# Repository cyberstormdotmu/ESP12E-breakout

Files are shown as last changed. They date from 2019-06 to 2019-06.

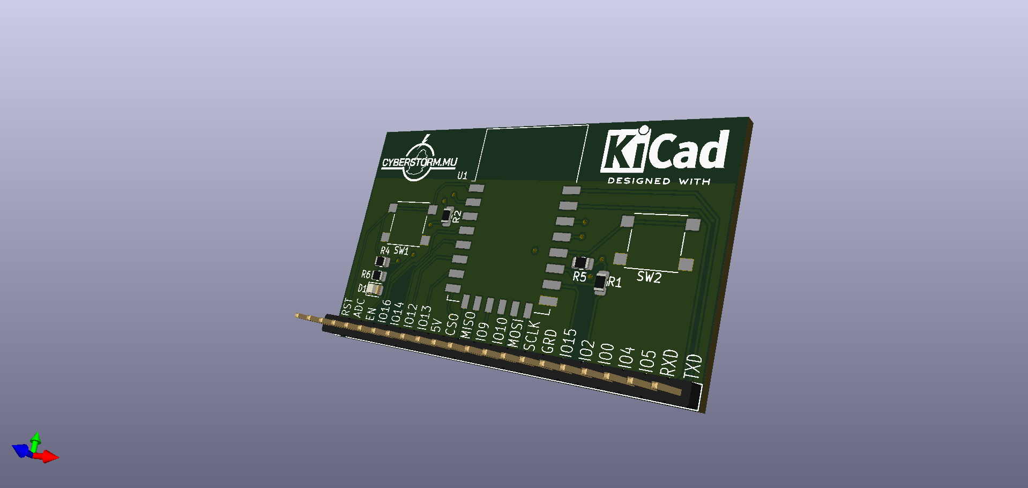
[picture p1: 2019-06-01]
ESP12-E breakout board.png

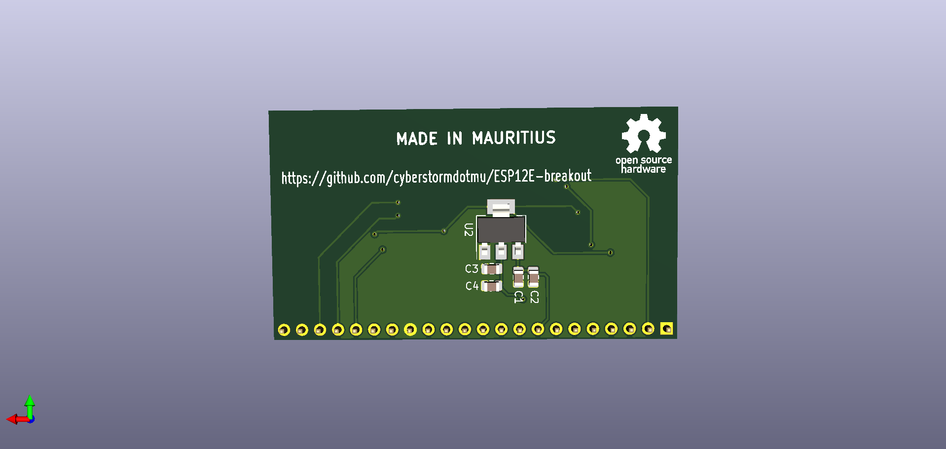
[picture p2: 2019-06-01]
ESP12-E breakout board(back).png

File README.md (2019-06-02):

# ESP12E-breakout
A simple and open source ESP12E/ ESP8266 breakout board. You will need an external programmer to program the module but most of the components required to run the module are present. Made with KiCad.

To open the schematic and pcb file you will need KiCad.

Schematic pdf and PCB photos are provided.

breakoutesp12e.zip is a gerber file.

If you have any questions regarding the design or find any issues then just email me at nathan@cyberstorm.mu

Happy Hacking :)

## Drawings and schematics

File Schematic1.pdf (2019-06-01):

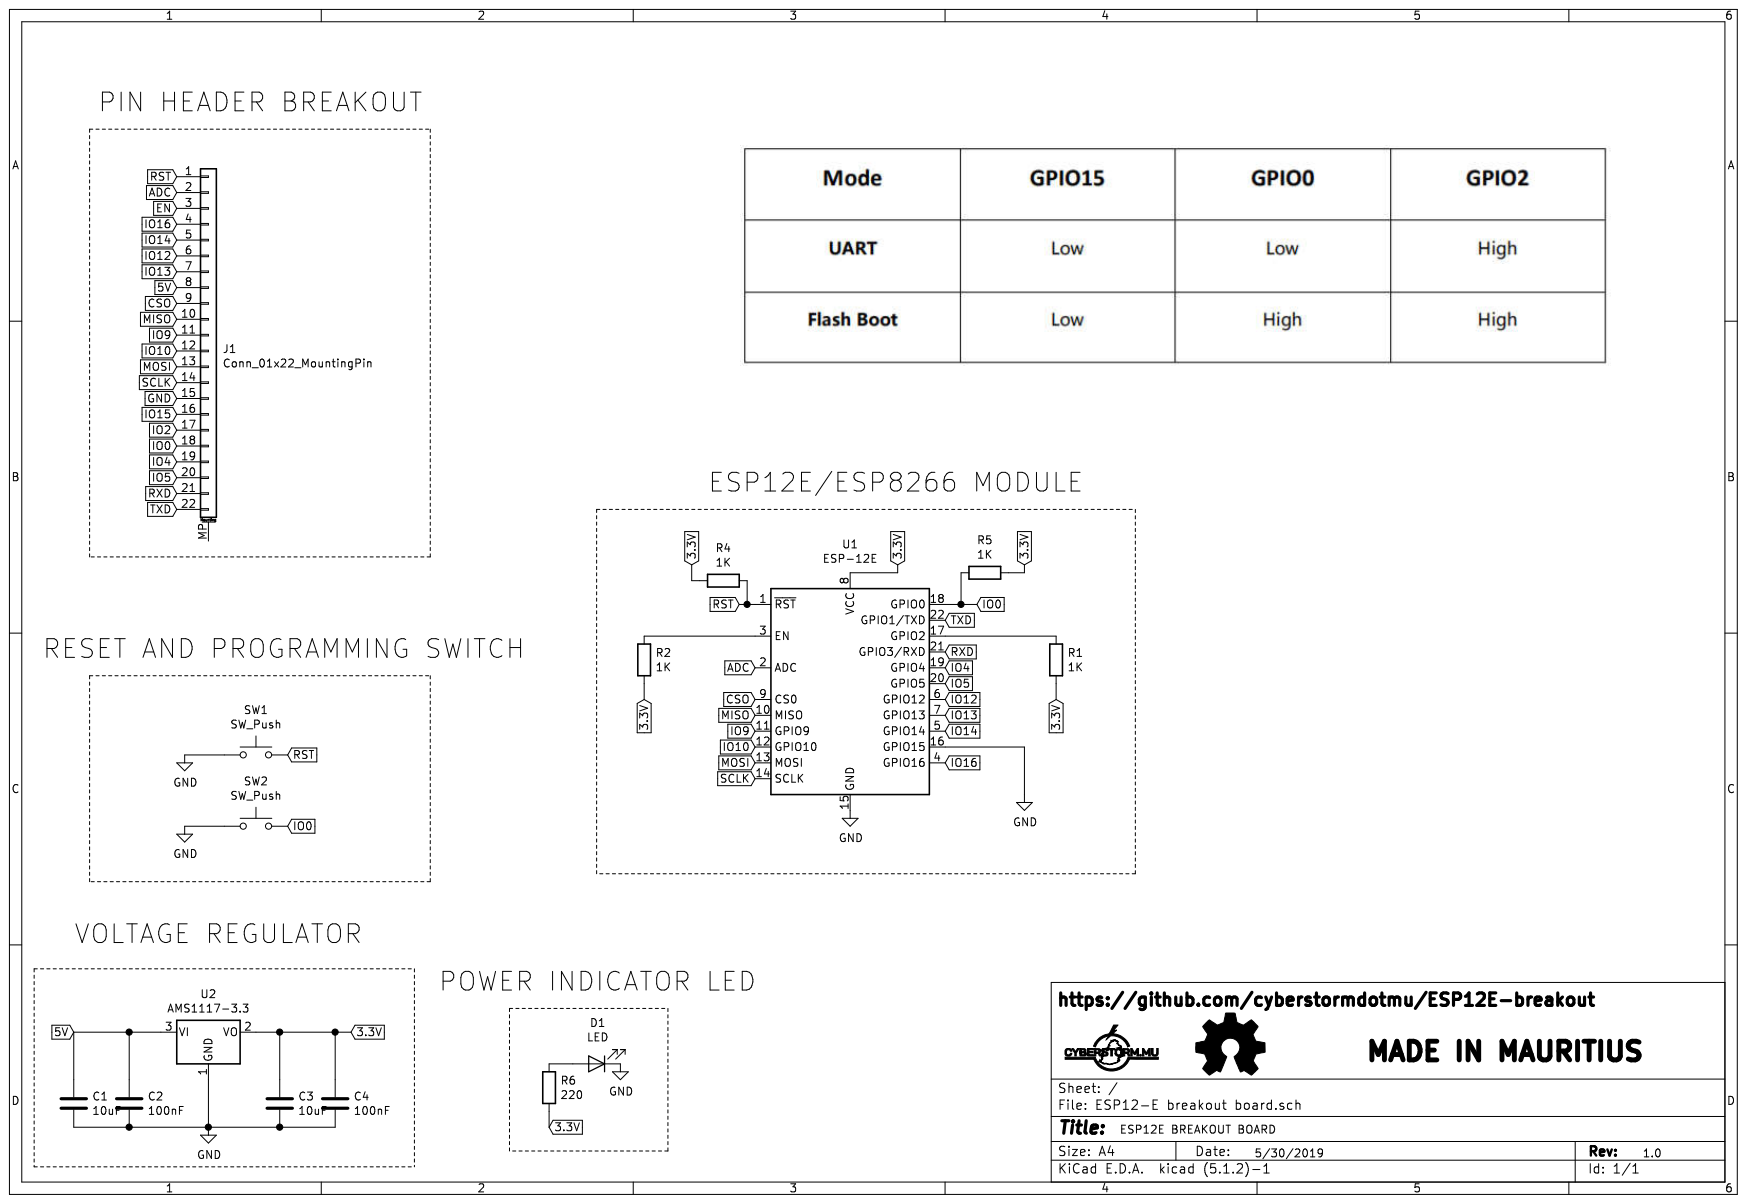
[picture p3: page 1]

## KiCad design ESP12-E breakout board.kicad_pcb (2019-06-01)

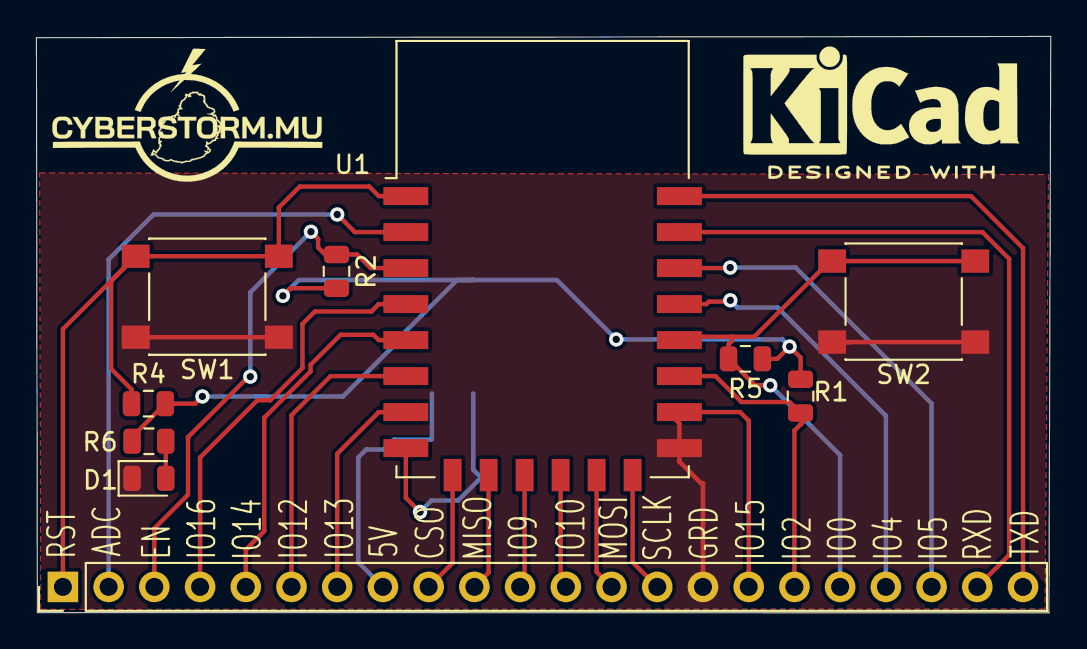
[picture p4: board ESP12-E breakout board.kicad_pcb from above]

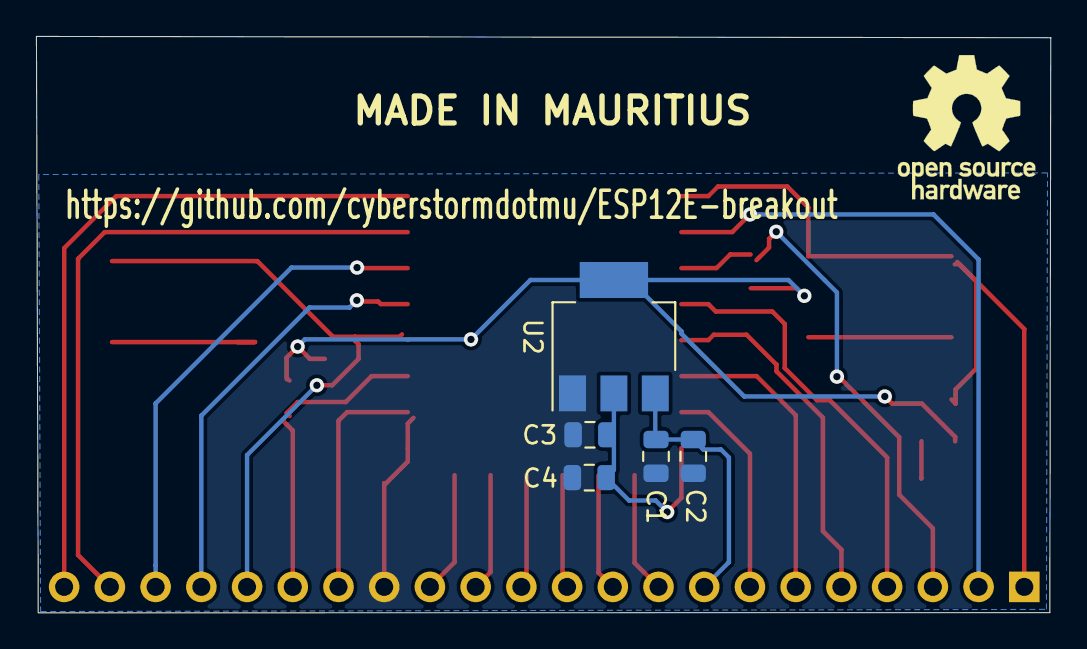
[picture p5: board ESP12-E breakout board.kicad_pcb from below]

Board: 2 copper layers, 56.3 x 32.0 mm, 15 parts (5 on the bottom side), 24 nets.

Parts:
C1, C3: 10uF; C_0805_2012Metric
C2, C4: 100nF; C_0805_2012Metric
D1: LED; LED_0805_2012Metric
J1: Conn_01x22_MountingPin; PinHeader_1x22_P2.54mm_Vertical
R1, R2, R4, R5: 1K; R_0805_2012Metric
R6: 220; R_0805_2012Metric
SW1, SW2: SW_Push; SW_Push_1P1T_NO_6x6mm_H9.5mm
U1: ESP-12E
U2: AMS1117-3.3; SOT-223-3_TabPin2

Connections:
3.3V: C3.1, C4.1, R1.2, R2.2, R4.2, R5.1, R6.2, U1.8, U2.2
5V: C1.1, C2.1, J1.8, U2.3
ADC: J1.2, U1.2
CSO: J1.9, U1.9
GND: C1.2, C2.2, C3.2, C4.2, D1.1, J1.15, SW1.1, SW2.1, U1.15, U2.1
IO0: J1.18, R5.2, SW2.2, U1.18
IO2: J1.17, R1.1
IO4: J1.19, U1.19
IO5: J1.20, U1.20
IO9: J1.11, U1.11
IO10: J1.12, U1.12
IO12: J1.6, U1.6
IO13: J1.7, U1.7
IO14: J1.5, U1.5
IO15: J1.16, U1.16
IO16: J1.4, U1.4
MISO: J1.10, U1.10
MOSI: J1.13, U1.13
unnamed: D1.2, R6.1
unnamed: R2.1, U1.3
RST: J1.1, R4.1, SW1.2, U1.1
RXD: J1.21, U1.21
SCLK: J1.14, U1.14
TXD: J1.22, U1.22

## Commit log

2019-05-30 Delete ESP12-E breakout board.sch
    Logo missing
    [ESP12-E breakout board.sch]
2019-05-30 Add files via upload
    Logo added
    [ESP12-E breakout board.sch]
2019-05-30 Add files via upload
    PDF of schematic ( logo not appearing )
2019-06-01 Add files via upload
    changes done to logos, schematics and added PCB layout
    [ESP12-E breakout board.kicad_pcb, ESP12-E breakout board.sch]
2019-06-01 Delete ESP12-E breakout board.kicad_pcb
    Random copper text on top layer
    [ESP12-E breakout board.kicad_pcb]
2019-06-01 Add files via upload
    Random copper text removed
    [ESP12-E breakout board.kicad_pcb]
2019-06-01 Add files via upload
    Gerber files added
2019-06-01 Add files via upload
    Board and schematics modified due to some errors found during testing
    [ESP12-E breakout board.kicad_pcb, ESP12-E breakout board.sch]
